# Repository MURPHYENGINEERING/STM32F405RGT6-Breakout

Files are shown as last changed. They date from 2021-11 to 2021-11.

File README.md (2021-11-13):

# Phil's STM32F4 Breakout board
Following along with [this excellent video](https://www.youtube.com/watch?v=t5phi3nT8OU) from [Phil's Lab](https://www.youtube.com/channel/UCVryWqJ4cSlbTSETBHpBUWw)

Also check out his very cool [fixed wing](http://philsal.co.uk/projects/uav/fixed-wing-flight-control-system) and [multirotor projects](http://philsal.co.uk/projects/uav/hadesmicro-quadcopter-flight-control-system).

[Please consider supporting his work by becoming a patron.](https://www.patreon.com/phils94)

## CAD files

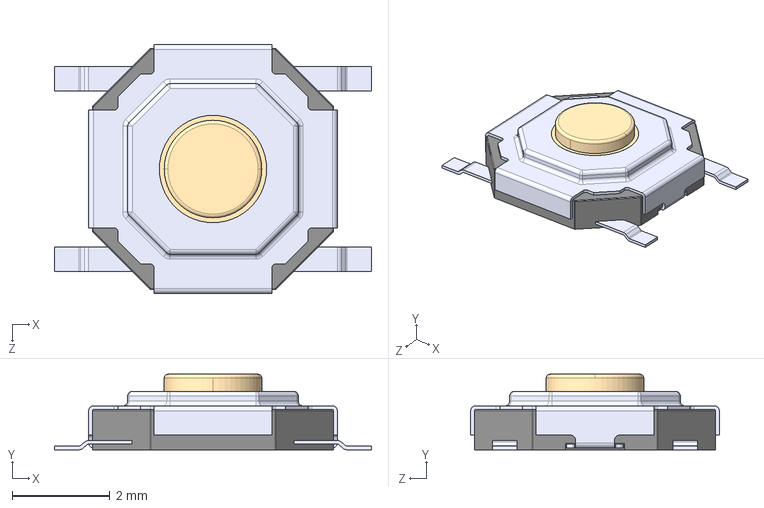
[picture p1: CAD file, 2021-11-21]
kicad/footprint/TS-1187A-B-A-B/TS-1187A-B-A-B.step
6.50 x 1.55 x 5.10 mm

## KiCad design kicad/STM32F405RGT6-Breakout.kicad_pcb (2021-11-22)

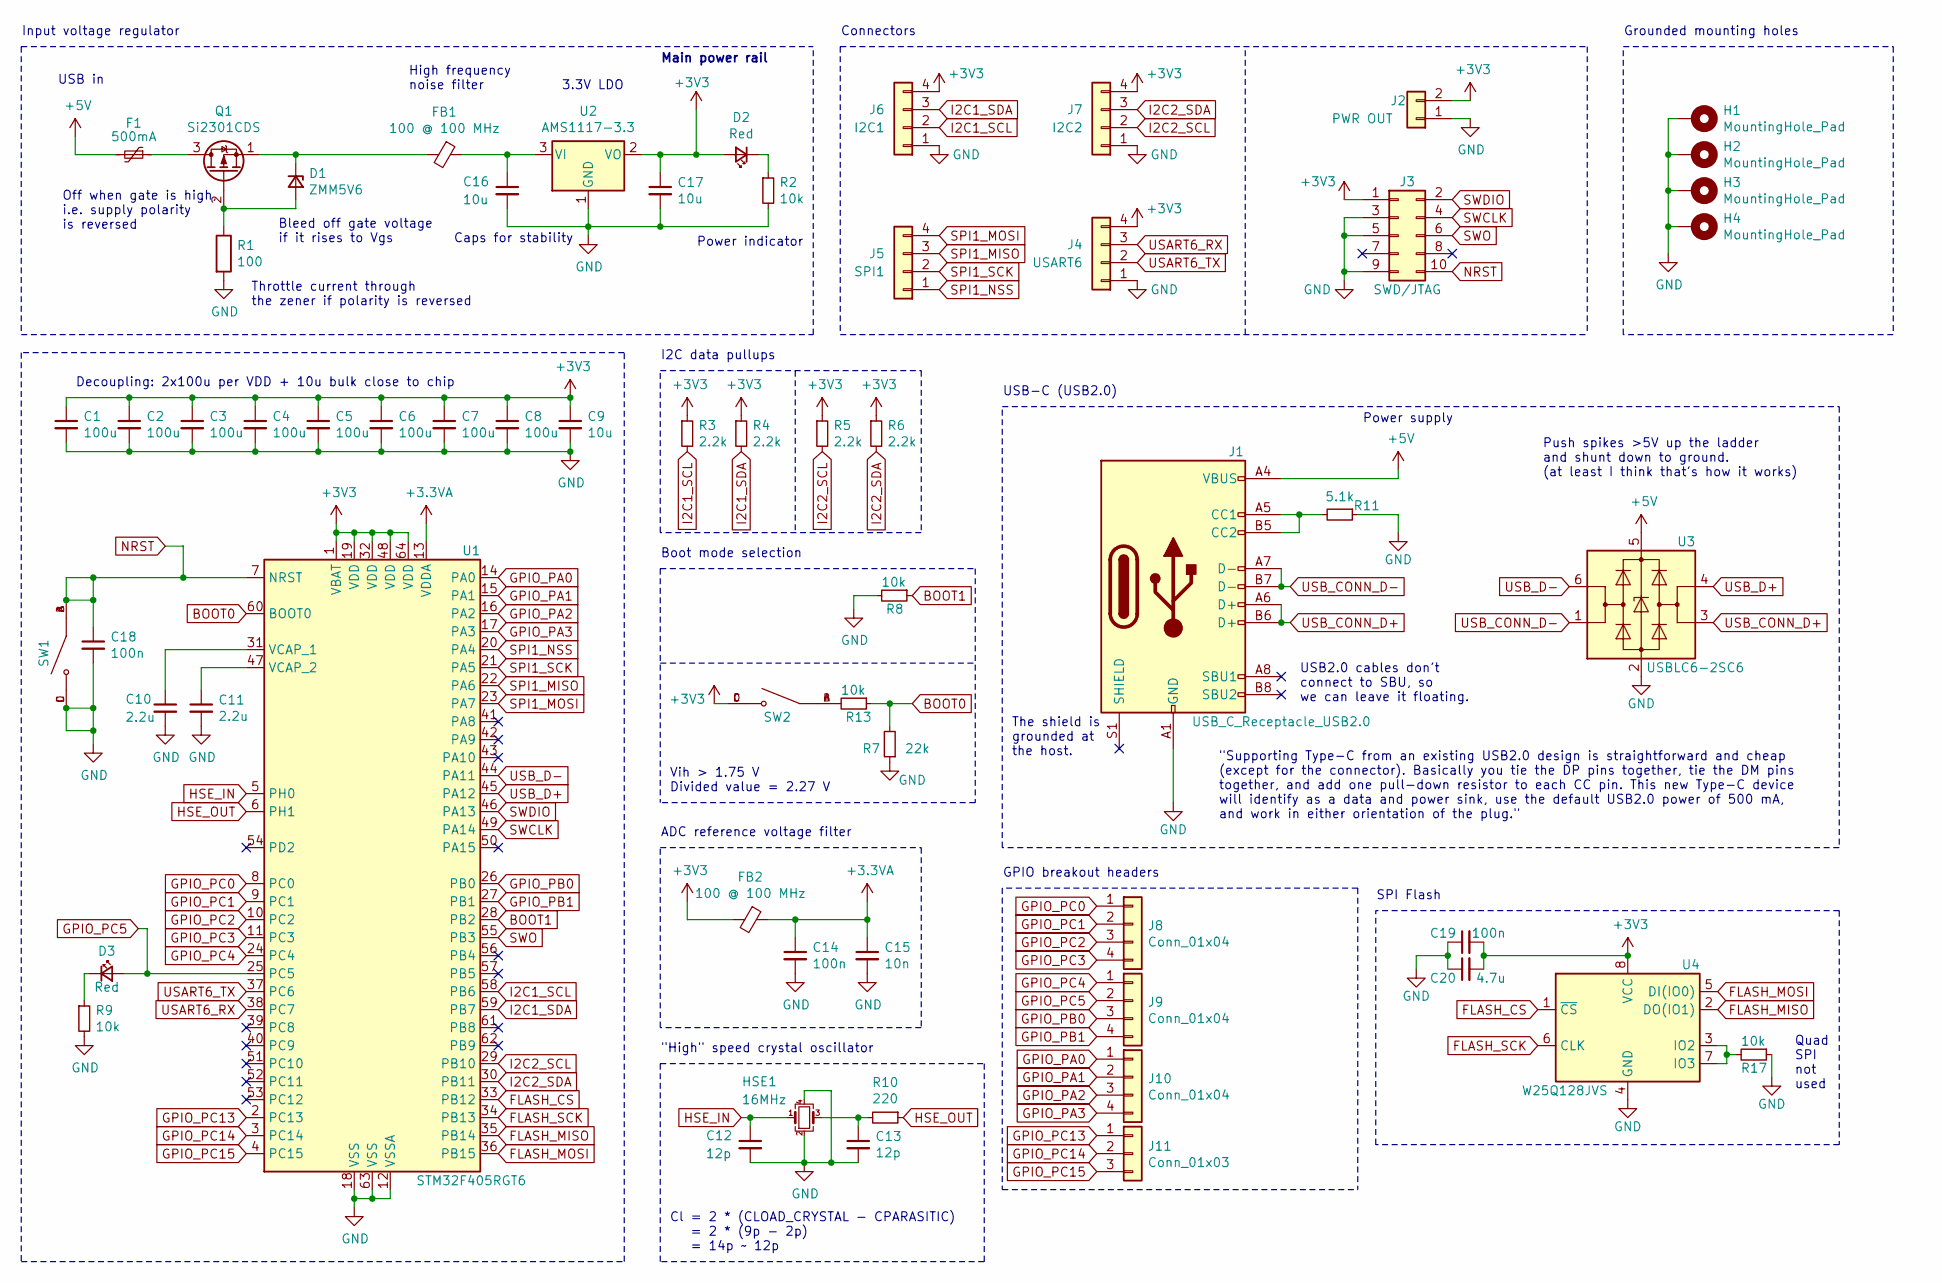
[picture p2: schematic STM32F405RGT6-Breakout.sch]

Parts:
C1, C2, C3, C4, C5, C6, C7, C8: 100u; C_0402_1005Metric
C9: 10u; C_0603_1608Metric
C10, C11: 2.2u; C_0603_1608Metric
C12, C13: 12p; C_0402_1005Metric
C14, C18: 100n; C_0402_1005Metric
C15: 10n; C_0402_1005Metric
C16, C17: 10u; C_0805_2012Metric
C19: 100n; C_0603_1608Metric
C20: 4.7u; C_0805_2012Metric
D1: ZMM5V6; D_MiniMELF
D2, D3: Red; D_0603_1608Metric
F1: 500mA; Fuse_0603_1608Metric
FB1, FB2: 100 @ 100 MHz; L_0805_2012Metric; JLCPCB Part C1015
H1, H2, H3, H4: MountingHole_Pad; MountingHole_4.3mm_M4_Pad_Via
HSE1: 16MHz; Crystal_SMD_3225-4Pin_3.2x2.5mm; JLCPCB Part C160456
J1: USB_C_Receptacle_USB2.0; USB_C_Receptacle_XKB_U262-16XN-4BVC11; JLCPCB Part C319148
J2: PWR OUT; PinSocket_1x02_P2.54mm_Vertical_SMD_Pin1Left
J3: SWD/JTAG; PinSocket_2x05_P1.27mm_Vertical_SMD
J4: USART6; PinSocket_1x04_P2.54mm_Vertical_SMD_Pin1Left
J5: SPI1; PinSocket_1x04_P2.54mm_Vertical_SMD_Pin1Left
J6: I2C1; PinSocket_1x04_P2.54mm_Vertical_SMD_Pin1Left
J7: I2C2; PinSocket_1x04_P2.54mm_Vertical_SMD_Pin1Left
J8, J9, J10: Conn_01x04; PinSocket_1x04_P2.54mm_Vertical_SMD_Pin1Left
J11: Conn_01x03; PinSocket_1x03_P2.54mm_Vertical_SMD_Pin1Left
Q1: Si2301CDS; SOT-23; JLCPCB Part C10487
R1: 100; R_0805_2012Metric
R2, R9: 10k; R_0603_1608Metric
R3, R4, R5, R6: 2.2k; R_0402_1005Metric
R7: 22k; R_0603_1608Metric
R8, R13, R17: 10k; R_0402_1005Metric
R10: 220; R_0402_1005Metric
R11: 5.1k; R_0402_1005Metric
SW1, SW2: TS-1187A-B-A-B; SW_TS-1187A-B-A-B; PARTREV A0; JLCPCB Part C318884
U1: STM32F405RGT6; LQFP-64_10x10mm_P0.5mm; JLCPCB Part C15742
U2: AMS1117-3.3; SOT-223-3_TabPin2; JLCPCB Part C6186
U3: USBLC6-2SC6; SOT-23-6; JLCPCB Part C2827654
U4: W25Q128JVS; SOIC-8_5.23x5.23mm_P1.27mm; JLCPCB Part C97521

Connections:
+3.3VA: C14.1, C15.1, FB2.1, U1.13 (VDDA)
+3V3: C1.1, C2.1, C3.1, C4.1, C5.1, C6.1, C7.1, C8.1, C9.1, C17.1, C19.2, C20.2, D2.2 (A), FB2.2, J2.2, J3.1, J4.4, J6.4, J7.4, R3.1, R4.1, R5.1, R6.1, SW2.C, SW2.D, U1.1 (VBAT), U1.19 (VDD), U1.32 (VDD), U1.48 (VDD), U1.64 (VDD), U2.2 (VO), U4.8 (VCC)
+5V: F1.2, J1.A4 (VBUS), J1.A9 (VBUS), J1.B4 (VBUS), J1.B9 (VBUS), U3.5 (VBUS)
BOOT0: R7.2, R13.1, U1.60 (BOOT0)
BOOT1: R8.1, U1.28 (PB2)
FLASH_CS: U1.33 (PB12), U4.1 (~CS)
FLASH_MISO: U1.35 (PB14), U4.2 (DO(IO1))
FLASH_MOSI: U1.36 (PB15), U4.5 (DI(IO0))
FLASH_SCK: U1.34 (PB13), U4.6 (CLK)
GND: C1.2, C2.2, C3.2, C4.2, C5.2, C6.2, C7.2, C8.2, C9.2, C10.2, C11.2, C12.2, C13.2, C14.2, C15.2, C16.2, C17.2, C18.2, C19.1, C20.1, H1.1, H2.1, H3.1, H4.1, HSE1.2, HSE1.4, J1.A1 (GND), J1.A12 (GND), J1.B1 (GND), J1.B12 (GND), J2.1, J3.3, J3.5, J3.9, J4.1, J6.1, J7.1, R1.2, R2.2, R7.1, R8.2, R9.2, R11.1, R17.1, SW1.C, SW1.D, U1.12 (VSSA), U1.18 (VSS), U1.63 (VSS), U2.1 (GND), U3.2 (GND), U4.4 (GND)
GPIO_PA0: J10.1, U1.14 (PA0)
GPIO_PA1: J10.2, U1.15 (PA1)
GPIO_PA2: J10.3, U1.16 (PA2)
GPIO_PA3: J10.4, U1.17 (PA3)
GPIO_PB0: J9.3, U1.26 (PB0)
GPIO_PB1: J9.4, U1.27 (PB1)
GPIO_PC0: J8.1, U1.8 (PC0)
GPIO_PC1: J8.2, U1.9 (PC1)
GPIO_PC2: J8.3, U1.10 (PC2)
GPIO_PC3: J8.4, U1.11 (PC3)
GPIO_PC4: J9.1, U1.24 (PC4)
GPIO_PC5: D3.2 (A), J9.2, U1.25 (PC5)
GPIO_PC13: J11.1, U1.2 (PC13)
GPIO_PC14: J11.2, U1.3 (PC14)
GPIO_PC15: J11.3, U1.4 (PC15)
HSE_IN: C12.1, HSE1.1, U1.5 (PH0)
HSE_OUT: R10.1, U1.6 (PH1)
I2C1_SCL: J6.2, R3.2, U1.58 (PB6)
I2C1_SDA: J6.3, R4.2, U1.59 (PB7)
I2C2_SCL: J7.2, R5.2, U1.29 (PB10)
I2C2_SDA: J7.3, R6.2, U1.30 (PB11)
NRST: C18.1, J3.10, SW1.A, SW1.B, U1.7 (NRST)
unnamed: C10.1, U1.31 (VCAP_1)
unnamed: C11.1, U1.47 (VCAP_2)
unnamed: C13.1, HSE1.3, R10.2
unnamed: C16.1, FB1.1, U2.3 (VI)
unnamed: D1.1 (K), FB1.2, Q1.1 (S)
unnamed: D1.2 (A), Q1.2 (G), R1.1
unnamed: D2.1 (K), R2.1
unnamed: D3.1 (K), R9.1
unnamed: F1.1, Q1.3 (D)
unnamed: J1.A5 (CC1), J1.B5 (CC2), R11.2
unnamed: R13.2, SW2.A, SW2.B
unnamed: R17.2, U4.3 (IO2), U4.7 (IO3)
SPI1_MISO: J5.3, U1.22 (PA6)
SPI1_MOSI: J5.4, U1.23 (PA7)
SPI1_NSS: J5.1, U1.20 (PA4)
SPI1_SCK: J5.2, U1.21 (PA5)
SWCLK: J3.4, U1.49 (PA14)
SWDIO: J3.2, U1.46 (PA13)
SWO: J3.6, U1.55 (PB3)
USART6_RX: J4.3, U1.38 (PC7)
USART6_TX: J4.2, U1.37 (PC6)
USB_CONN_D+: J1.A6 (D+), J1.B6 (D+), U3.3 (I/O2)
USB_CONN_D-: J1.A7 (D-), J1.B7 (D-), U3.1 (I/O1)
USB_D+: U1.45 (PA12), U3.4 (I/O2)
USB_D-: U1.44 (PA11), U3.6 (I/O1)

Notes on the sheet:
Throttle current through the zener if polarity is reversed
Bleed off gate voltage if it rises to Vgs
Caps for stability
High frequency noise filter
3.3V LDO
Cl = 2 * (CLOAD_CRYSTAL - CPARASITIC) = 2 * (9p - 2p) = 14p ~~ 12p
ADC reference voltage filter
Input voltage regulator
"High" speed crystal oscillator
Decoupling: 2x100u per VDD + 10u bulk close to chip
Off when gate is high, i.e. supply polarity is reversed
Connectors
I2C data pullups
Grounded mounting holes
Power indicator
USB in
Main power rail
"Supporting Type-C from an existing USB2.0 design is straightforward and cheap (except for the connector). Basically you tie the DP pins together, tie the DM pins together, and add one pull-down resistor to each CC pin. This new Type-C device will identify as a data and power sink, use the default 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
The shield is grounded at the host.
USB-C (USB2.0)
USB2.0 cables don't connect to SBU, so we can leave it floating.
Push spikes >5V up the ladder and shunt down to ground. (at least I think that's how it works)
Quad SPI not used
SPI Flash
Boot mode selection
Power supply
Vih > 1.75 V Divided value = 2.27 V
GPIO breakout headers

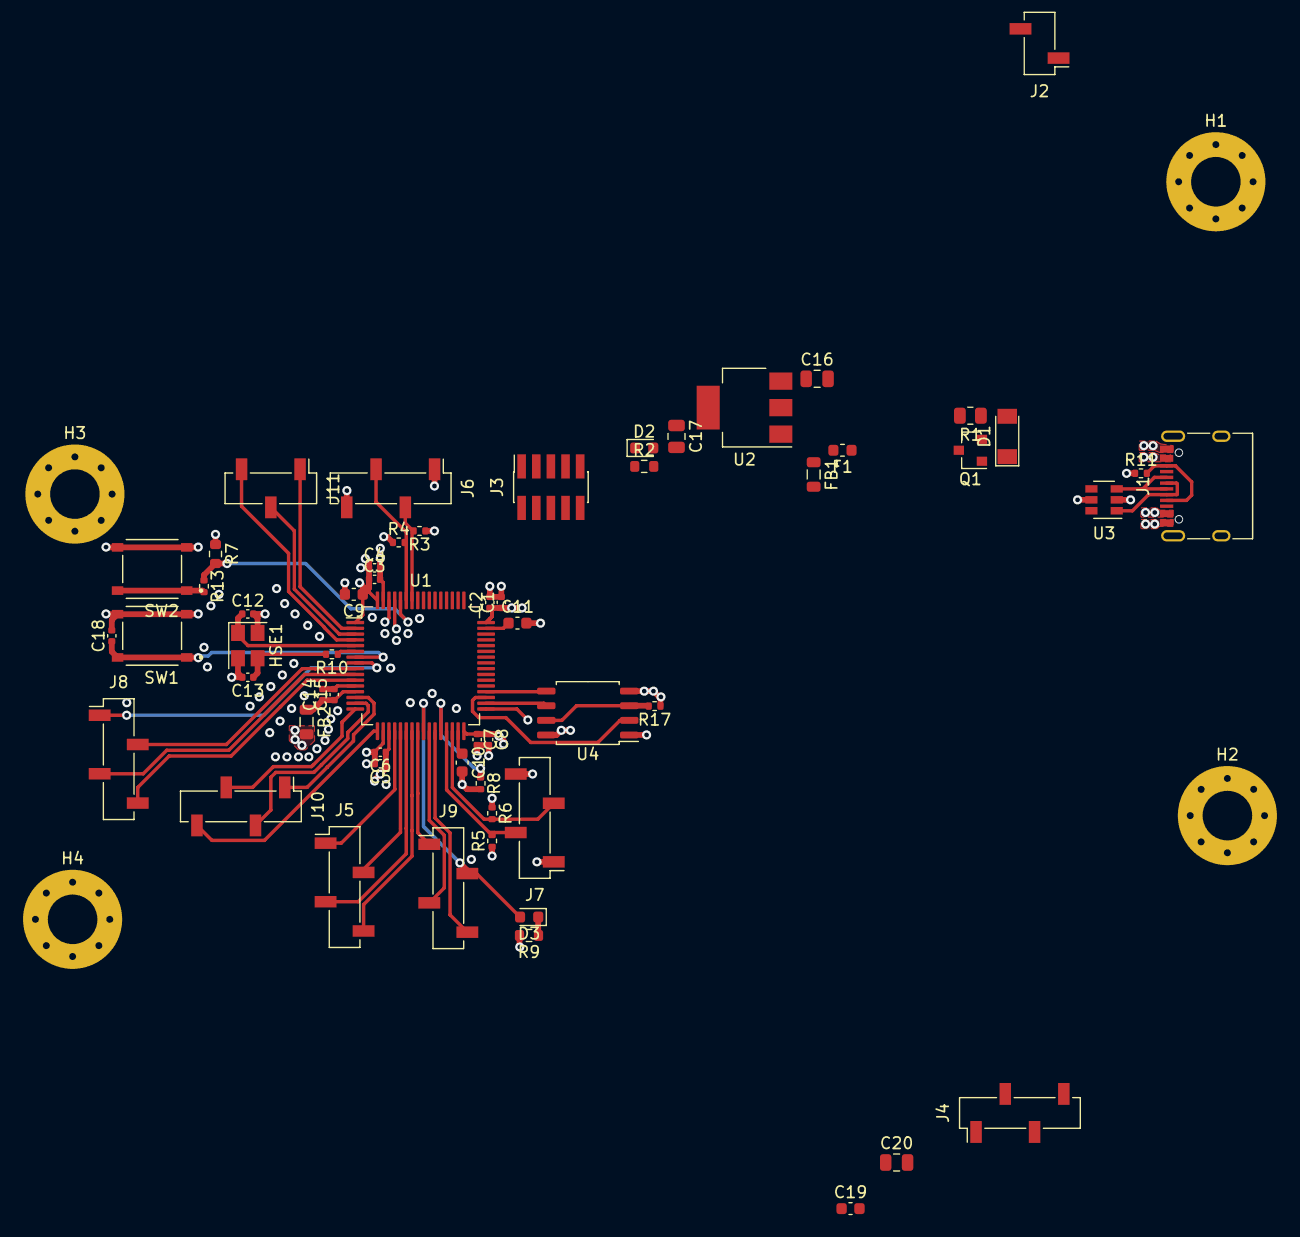
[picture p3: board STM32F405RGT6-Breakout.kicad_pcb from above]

Board: 4 copper layers, 62 parts (0 on the bottom side), 57 nets.

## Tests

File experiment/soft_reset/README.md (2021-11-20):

# Soft-reset experiments

Exploring methods to soft-reset the STM32F4xx so we don't have to manually
boot into DFU every time we flash it.

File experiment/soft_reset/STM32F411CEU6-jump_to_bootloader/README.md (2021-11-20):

# Soft reset: jump to bootloader in system memory

The code below is taken from [Akos Pasztor's](https://github.com/akospasztor) 
[STM32 Bootloader](https://github.com/akospasztor/stm32-bootloader).

Seems to work just fine! I have no idea if there are any traps here.

I can also restart the existing user code with no obvious problems, but I haven't
enabled any peripherals (`STM32_Programmer_CLI.exe -c port=usb1 -s 0x08000000`).

[bootloader.c#L439](https://github.com/akospasztor/stm32-bootloader/blob/7472c7b439d1921ecf9b835bc8e85b53c0549aa9/lib/stm32-bootloader/bootloader.c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):

```cpp
typedef void (*pFunction)(void);

#define SYSMEM_ADDRESS 0x1FFF0000

/**
 * @brief  This function performs the jump to the MCU System Memory (ST
 *         Bootloader).
 * @details The function carries out the following operations:
 *  - De-initialize the clock and peripheral configuration
 *  - Stop the systick
 *  - Remap the system flash memory
 *  - Perform the jump
 */
void jump_to_bootloader()
{
  uint32_t JumpAddress = *(__IO uint32_t*)(SYSMEM_ADDRESS + 4);
  pFunction Jump       = (pFunction)JumpAddress;

  HAL_RCC_DeInit();
  HAL_DeInit();

  SysTick->CTRL = 0;
  SysTick->LOAD = 0;
  SysTick->VAL  = 0;

  __HAL_RCC_SYSCFG_CLK_ENABLE();
  __HAL_SYSCFG_REMAPMEMORY_SYSTEMFLASH();

  __set_MSP(*(__IO uint32_t*)SYSMEM_ADDRESS);
  Jump();

  while(1)
      ;
}
```

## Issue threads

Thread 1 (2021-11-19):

Support software reset over USB for programming from Arduino IDE without BOOT0 pin

MURPHYENGINEERING, 2021-11-19:
Reading about FTDI programming with a bootloader:

RS-232 chips use the DTR pin to reset the chip and enter the bootloader's firmware-receptive window:

> The DTR signal is present on pin 20 of the 22-wire RS-232 interface using a DB-25 connector, and on pin 4 of a newer DE-9 serial port. The signal is asserted (logic "1") by raising the voltage of the pin from negative to positive. [https://en.wikipedia.org/wiki/Data_Terminal_Ready](link)

That pin is toggled when the IDE starts uploading (or opens the serial monitor) and stays high. The reset pulse is implemented by draining a capacitor on the chip reset pin:

> On the hardware side, the DTR pin is connected to one side of a 0.1uf ceramic capacitor. The other side of that 0.1uf ceramic capacitor is connected to the RST pin on the AVR, and pulled up with a 10k resistor to Vcc. (thanks [DrAzzy](https://forum.arduino.cc/u/DrAzzy) on [forum.arduino.cc](https://forum.arduino.cc/t/how-to-make-a-dtr-reset/385699))

To support that process on the STM32, we need to find how the FTDI chip translates the always-connected USB channel to a toggling DTR signal. Can the host-side driver toggle power on the USB interface? That seems almost too easy.

Briefly looking at the Arduino UNO schematic, it looks like they're using an ATMEGA16 as an ISP connected directly to USB.

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

On the [datasheet](https://ww1.microchip.com/downloads/en/DeviceDoc/doc7799.pdf) there's a good clue about how this might work:
> – Microcontroller reset on USB Bus Reset without detach

The ATMEGA16 appears to be using something like that DTR reset scheme:

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

More after class

MURPHYENGINEERING, 2021-11-20:
We can use the built-in bootloader to flash it without a programmer, but the user has to boot it with the BOOT0 pin. Asking the user to put it in a special mode every time they want to upload code isn't what I want. We can require this the first time to flash a bootloader that listens for a programmer on USB so they have a more Arduino-like experience.

See the STM docs on the boot capabilities for our chip (c20ec9f2251de8fd79f439a7f0a2a60e13dd4db3). What we're looking for is

- If we get into system memory boot mode, can we program via the USB interface or do we need to add a USB to serial adapter to the board?
  - In CubeMX there's USB middleware that mentions DFU. Does that mean there's no USB DFU support otherwise?
- When we can program via USB, can we update the bootloader straight from Arduino/PlatformIO without downloading another programmer?
- If we do need some other programmer, can we bundle it into native packages for those IDEs?
  - How annoying will cross-platform support be?

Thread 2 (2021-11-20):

How does booting & programming work?

MURPHYENGINEERING, 2021-11-20:
The bootloader located in system memory (0x1FFFF 0000 - 0x1FFF 7A0F) supports DFU for USB programming. We can get into this mode initially by providing a way to connect BOOT0 high on reset (the black pill uses a button next to the reset button which is nice).

(application notes p. 27, fa90de39ef07cd1ccf2621360324945488009e36):

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

(application notes p. 26, fa90de39ef07cd1ccf2621360324945488009e36):

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

(datasheet p. 71, 346b6096a41fd45c98dffbb8aaf3f6245f88b07b):

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

Pulldown resistor values (application notes p. 27, fa90de39ef07cd1ccf2621360324945488009e36):

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

- We can flash a new bootloader via DFU using STM32CubeProgrammer:
  - Read out user flash into a file (manual p. 84, 3c6da7e7dbf923876c9fa454a9fece9c6418fbe8):
```STM32_Programmer_CLI.exe -c port=usb1 -r 0x08000000 0xFFFFF "user.bin"```
  - Write a file into user flash (manual p. 83, 3c6da7e7dbf923876c9fa454a9fece9c6418fbe8):
```STM32_Programmer_CLI.exe -c port=usb1 -w "user.bin" 0x08000000```
   - Start executing the contents of user flash (manual p. 85, 3c6da7e7dbf923876c9fa454a9fece9c6418fbe8):
```STM32_Programmer_CLI.exe -c port=usb1 -s 0x08000000```

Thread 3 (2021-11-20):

USB2.0 interface

MURPHYENGINEERING, 2021-11-20:
(datasheet p. 186, 346b6096a41fd45c98dffbb8aaf3f6245f88b07b)

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

---

**ESD protection: ST USBLC6**

**JLPCB:** C2827654 (Tech Public, ST insufficient stock 11/19/2021) (Tech Public datasheet: 346d4038fc2d1c64e9e795c339edcedd7c012fe2)

(datasheet p. 6, c6ce96c327877af64969daaa0c9efcc651a96ec3)

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

(datasheet p. 9, c6ce96c327877af64969daaa0c9efcc651a96ec3)

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

(datasheet p. 11, c6ce96c327877af64969daaa0c9efcc651a96ec3)
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

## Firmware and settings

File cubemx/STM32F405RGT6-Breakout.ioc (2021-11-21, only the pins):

Mcu.UserName=STM32F405RGTx
PA0-WKUP.Signal=SYS_WKUP
PA11.Signal=USB_OTG_FS_DM
PA12.Signal=USB_OTG_FS_DP
PA13.Signal=SYS_JTMS-SWDIO
PA14.Signal=SYS_JTCK-SWCLK
PA4.Signal=SPI1_NSS
PA5.Signal=SPI1_SCK
PA6.Signal=SPI1_MISO
PA7.Signal=SPI1_MOSI
PB10.Signal=I2C2_SCL
PB11.Signal=I2C2_SDA
PB12.GPIO_Label=FLASH_CS
PB12.Signal=SPI2_NSS
PB13.GPIO_Label=FLASH_SCK
PB13.Signal=SPI2_SCK
PB14.GPIO_Label=FLASH_MISO
PB14.Signal=SPI2_MISO
PB15.GPIO_Label=FLASH_MOSI
PB15.Signal=SPI2_MOSI
PB3.Signal=SYS_JTDO-SWO
PB6.Signal=I2C1_SCL
PB7.Signal=I2C1_SDA
PC6.Signal=USART6_TX
PC7.Signal=USART6_RX
PH0-OSC_IN.GPIO_Label=HSE_IN
PH0-OSC_IN.Signal=RCC_OSC_IN
PH1-OSC_OUT.GPIO_Label=HSE_OUT
PH1-OSC_OUT.Signal=RCC_OSC_OUT

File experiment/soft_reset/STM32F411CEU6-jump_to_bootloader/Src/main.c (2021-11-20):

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
/* Includes ------------------------------------------------------------------*/
#include "main.h"
#include "usb_device.h"
#include "gpio.h"


void SystemClock_Config(void);
/* USER CODE BEGIN 0 */
typedef void (*pFunction)(void);

#define SYSMEM_ADDRESS 0x1FFF0000

void jump_to_bootloader()
{
  uint32_t JumpAddress = *(__IO uint32_t*)(SYSMEM_ADDRESS + 4);
  pFunction Jump       = (pFunction)JumpAddress;

  HAL_RCC_DeInit();
  HAL_DeInit();

  SysTick->CTRL = 0;
  SysTick->LOAD = 0;
  SysTick->VAL  = 0;

  __HAL_RCC_SYSCFG_CLK_ENABLE();
  __HAL_SYSCFG_REMAPMEMORY_SYSTEMFLASH();

  __set_MSP(*(__IO uint32_t*)SYSMEM_ADDRESS);
  Jump();

  while(1)
      ;
}
/* USER CODE END 0 */

/**
  * @brief  The application entry point.
  * @retval int
  */
int main(void)
{
  /* MCU Configuration--------------------------------------------------------*/

  /* Reset of all peripherals, Initializes the Flash interface and the Systick. */
  HAL_Init();

  /* Configure the system clock */
  SystemClock_Config();

  /* Initialize all configured peripherals */
  MX_GPIO_Init();
  MX_USB_DEVICE_Init();
  /* USER CODE BEGIN 2 */

  HAL_GPIO_WritePin(LED_GPIO_Port, LED_Pin, GPIO_MODE_OUTPUT_PP);
  unsigned int count = 0;
  /* USER CODE END 2 */

  /* Infinite loop */
  /* USER CODE BEGIN WHILE */
  while (1)
  {
    HAL_GPIO_TogglePin(LED_GPIO_Port, LED_Pin);
    HAL_Delay(500);
    if (++count > 5) {
      jump_to_bootloader();
    }
    /* USER CODE END WHILE */

    /* USER CODE BEGIN 3 */
  }
  /* USER CODE END 3 */
}

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


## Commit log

2021-11-13 KiCad project
    [STM32F405RGT6-Breakout.kicad_pcb, STM32F405RGT6-Breakout.sch]
2021-11-15 Input voltage regulator with pch input reverse polarity protection
    [STM32F405RGT6-Breakout.sch]
2021-11-15 ADC voltage reference filter
    [STM32F405RGT6-Breakout.sch]
2021-11-15 boot mode pins
    [STM32F405RGT6-Breakout.sch]
2021-11-15 Configure pins for high speed crystal
    [STM32F405RGT6-Breakout.sch]
2021-11-15 Crystal oscillator
    [STM32F405RGT6-Breakout.sch]
2021-11-15 Hook up serial wire debug & enable on chip
    [STM32F405RGT6-Breakout.sch]
2021-11-15 fixed an unconnected pin
    [STM32F405RGT6-Breakout.sch]
2021-11-15 - add JTAG/SWD connector - configure USB pins on chip
    [STM32F405RGT6-Breakout.sch]
2021-11-15 communication pins labeled
    [STM32F405RGT6-Breakout.sch]
2021-11-16 - i2c pullups - connectors laid out - added 3v3 and gnd to i2c connectors - working on adding USB
    [STM32F405RGT6-Breakout.sch]
2021-11-16 get rid of Vin, we'll use USB only
    [STM32F405RGT6-Breakout.sch]
2021-11-16 - USB-C connector wired in with ESD protection. - We can't get the USBLC6-2SC6 chip except in full reels, so sub in the IP4220CZ6 (https://datasheet.lcsc.com/lcsc/1810121050_Nexperia-IP4220CZ6,125_C2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
    - Still looking for a USB connector that's available in 1+ qty and has a footprint we can get
    [STM32F405RGT6-Breakout.sch]
2021-11-16 the power flags thing is stupid
    [STM32F405RGT6-Breakout.sch]
2021-11-16 - Start assigning footprints for the major components o I was wrong about the pricing at JLCPCB; we don't have to buy a reel to do board assembly. - Still need to work out sizes for passives based on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
    [STM32F405RGT6-Breakout.sch]
2021-11-20 Built-in bootloader docs for maybe flashing a more arduino-friendly bootloader
2021-11-20 STM32CubeProgrammer user guide
2021-11-20 Started adding a 128mb NOR flash, but eh... why? They're basic parts at JLCPCB so it might be worth it just to try interfacing with it and see what's going on there. It seems pretty idiot proof hardw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
    [STM32F405RGT6-Breakout.sch]
2021-11-20 clarify what software the board files are for
    [STM32F405RGT6-Breakout.kicad_pcb, STM32F405RGT6-Breakout.sch]
2021-11-21 Application note for SPI flash decoupling
2021-11-21 - Added onboard SPI flash, just to experiment with (128mb NOR flash is basic part at JLCPCB) - Added momentary switches for BOOT0 and NRST to get into DFU mode, like the black pill - Added a capacito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
    [STM32F405RGT6-Breakout.sch]
2021-11-21 nix the SD card slot, I can't imagine trying to route that right now
2021-11-21 Half way done with footprint assignment
    [STM32F405RGT6-Breakout.sch]
2021-11-21 USB connector datasheet
2021-11-21 - Added SPST tact switch symbol & footprint from JLPCB - Used SPST to ground NRST for reset - Used SPST to raise BOOT0 for DFU - BOOT0 on voltage divider, should work with the switch bringing BOOT0 t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
    [STM32F405RGT6-Breakout.sch, TS-1187A-B-A-B.step]
2021-11-21 Rough layout functional groups
    [STM32F405RGT6-Breakout.kicad_pcb]
2021-11-21 - Laid out & routed crystal - Laid out & started routing MCU decoupling
    --> Checkpoint before trying new flash orientation
    [STM32F405RGT6-Breakout.kicad_pcb, STM32F405RGT6-Breakout.sch]
2021-11-21 This flash SPI routing is definitely better
    [STM32F405RGT6-Breakout.kicad_pcb]
2021-11-22 - USB connector & ESD protection laid out - Crystal moved to make room for fanning out GPIO pins
    [STM32F405RGT6-Breakout.kicad_pcb, STM32F405RGT6-Breakout.sch]
2021-11-22 - Lots of GPIO breakouts wired up - Lots of signal isolation vias that I'm completely guessing about
    Still to lay out and route: power, USB, UART, SWD
    [STM32F405RGT6-Breakout.kicad_pcb, STM32F405RGT6-Breakout.sch]
2021-11-22 Checkpoint before starting over because too many afterthoughts piling up wrt. connectors
    [STM32F405RGT6-Breakout.kicad_pcb]

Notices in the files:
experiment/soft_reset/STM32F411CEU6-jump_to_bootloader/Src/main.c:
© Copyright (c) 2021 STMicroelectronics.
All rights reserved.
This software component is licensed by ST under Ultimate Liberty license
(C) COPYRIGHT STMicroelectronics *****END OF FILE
